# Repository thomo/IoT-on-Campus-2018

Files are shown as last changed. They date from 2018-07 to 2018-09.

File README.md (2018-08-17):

Boards, sources and configuration to run the Mini-Hackathon at SQS Campus 2018.
The infrastructure consists of two kind of ESP8266 nodes - called NodeA and NodeB - and a master. The master is running on a Raspberry Pi 3. On the master a bundle of applications is installed:
- Mosquitto - a MQTT server
- Influxdb - a time based database
- Grafana 
- NodeRed

The NodeA/NodeB are small IoT devices with a temperature/humidity/pressure sensor, two switches and some RGB leds. While NodeA is prebuild and will be distributed on the campus location to collect sensor data the NodeB will be put together by the participants in a workshop.

## Setup Arduino for ESP8266

(Source: https://github.com/esp8266/Arduino)

- Install the current upstream Arduino IDE at the 1.8 level or later. The current version is at the Arduino website.
- Start Arduino and open Preferences window.
- Enter http://arduino.esp8266.com/stable/package_esp8266com_index.json into Additional Board Manager URLs field. You can add multiple URLs, separating them with commas.
- Open Boards Manager from Tools > Board menu and install esp8266 platform (and don't forget to select your ESP8266 board from Tools > Board menu after installation).

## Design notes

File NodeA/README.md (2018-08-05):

# Circuit

A ESP8266 node with
- 2x WS2812A RGB LEDs, DIN on D5 (GPIO14)
- 2x switchs on D6 (GPIO12) and D7 (GPIO13) with 10k pull-ups
- 1x BME280, SCL on D1 (GPIO05) and SDL on D2 (GPIO04)

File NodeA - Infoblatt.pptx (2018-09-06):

## IoT (Internet of Things) – Node A SQS – Blackbox – Umwelt- und Sensordaten Infoblatt

- IoT Hackathon

© SQS Software Quality Systems AG | IoT Hackathon | Intern | Version 1.0 |

Push the Buttons

Messung von Temperatur, Luftfeuchtigkeit und Luftdruck im Raum

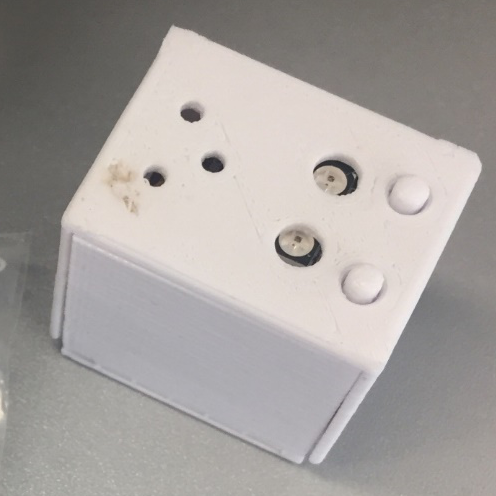
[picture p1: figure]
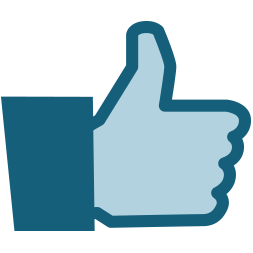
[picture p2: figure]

IoT WLAN:
SSID: “IoT Campus”
PW: “campus2018”
→ http://10.0.0.1:1880/ui

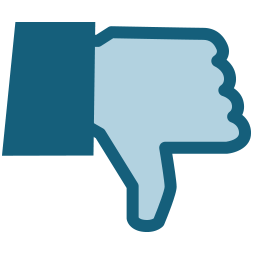
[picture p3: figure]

*Im Raum sind 6 NodeA verfügbar, welche über WLAN mit einem MQTT-Broker kommunizieren

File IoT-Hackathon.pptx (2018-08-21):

## IoT-Hackathon

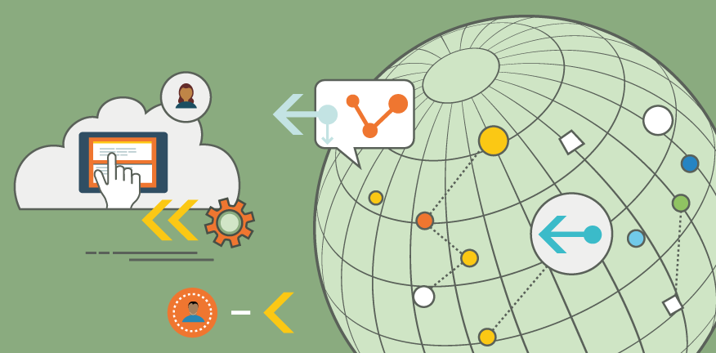
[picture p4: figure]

Transforming the World Through Quality

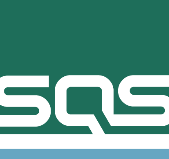
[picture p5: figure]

sqs.com

## Systemübersicht

© SQS Software Quality Systems AG | IoT Hackathon | Intern | Version 1.0 |

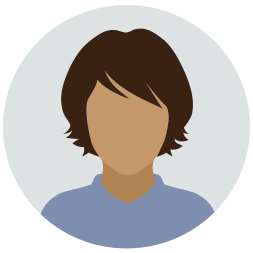
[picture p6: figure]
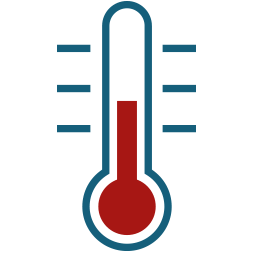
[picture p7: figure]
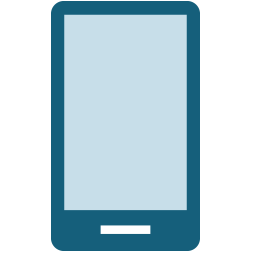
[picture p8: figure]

Sensor
BME280
Temperatur
Feuchtigkeit
Druck

Onewire

Sensor
Taster
2x

DIGITAL

Aktor
RGB LED
2x bzw.
LED Ring

DIGITAL

MQTT Publisher &
Subscriber
Node-Red
Raspberry PI

DASHBOARD
GRAFANA
Raspberry PI

MQTT Publisher
& Subscriber
WEMOS D1
ESP8266
NodeA / NodeB

MQTT

MQTT

HTTP

MQTT

MQTT Broker
Mosquitto
Raspberry PI

TIMEBASED DB
INFLUXDB
Raspberry PI

MQTT

HTTP

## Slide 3

NodeA

NodeA

NodeA

NodeA

NodeA

NodeA

Node-Red

GRAFANA

MOSQITTO

INFLUX DB

NodeB

NodeB

NodeB

NodeB

NodeB

NodeB

NodeB

NodeB

## Node A - Hardware

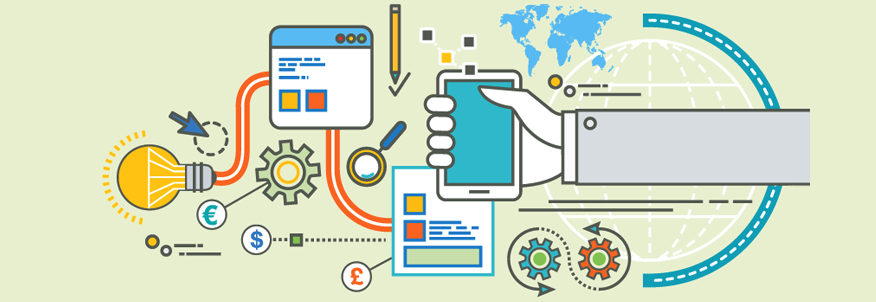
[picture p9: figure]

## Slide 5

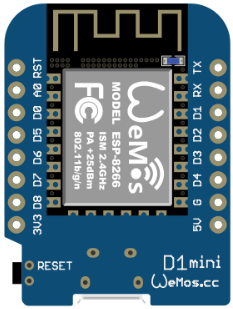
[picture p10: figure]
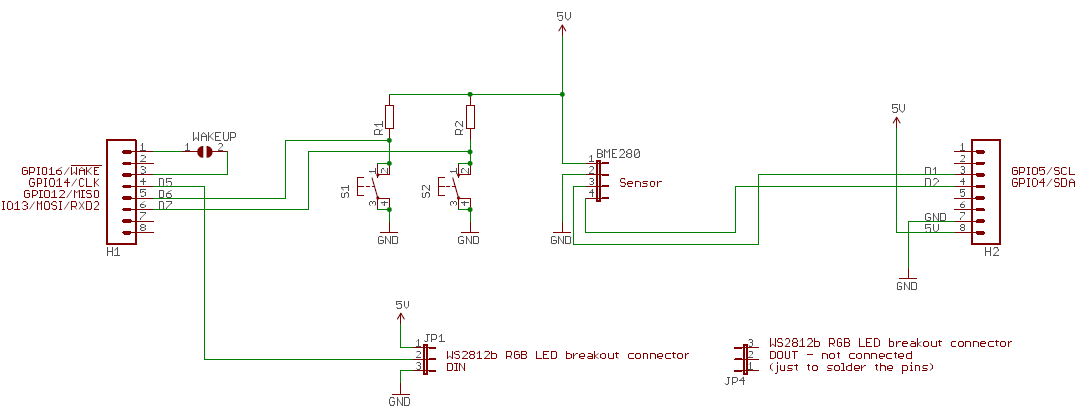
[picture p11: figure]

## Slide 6

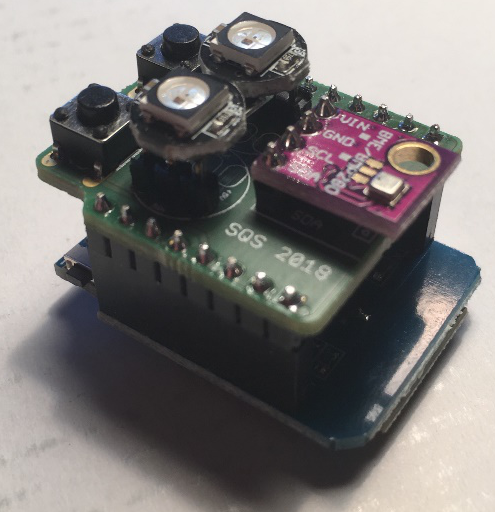
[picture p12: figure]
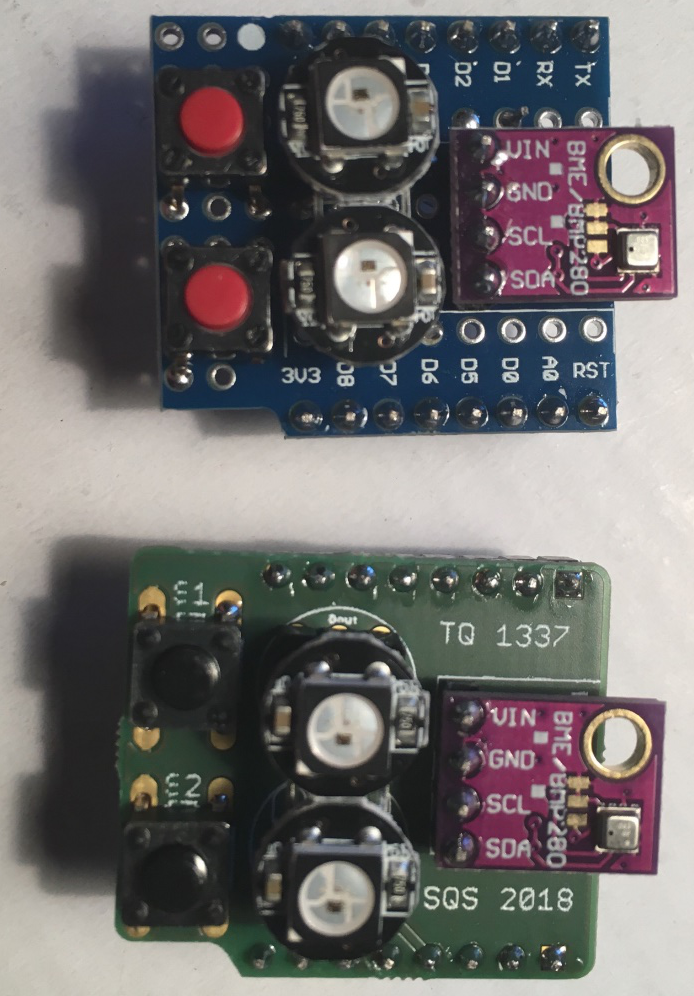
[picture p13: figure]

## Node B - Hardware

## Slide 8

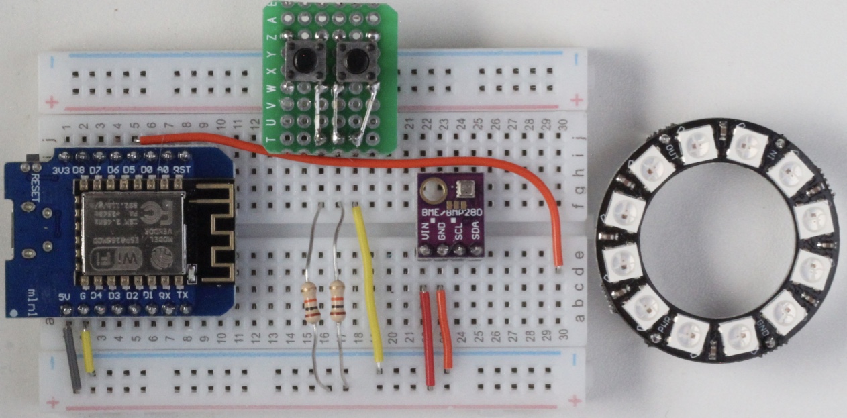
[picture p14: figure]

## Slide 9

IN

PWR

GND

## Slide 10

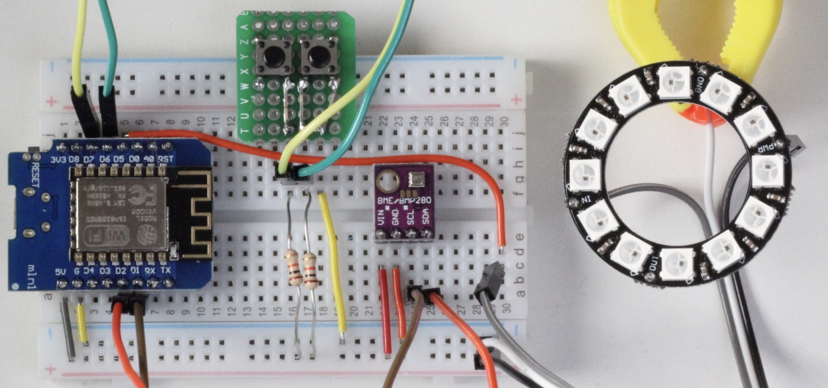
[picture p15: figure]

## Software

## Programmierung mit der Arduino Entwicklungsumgebung

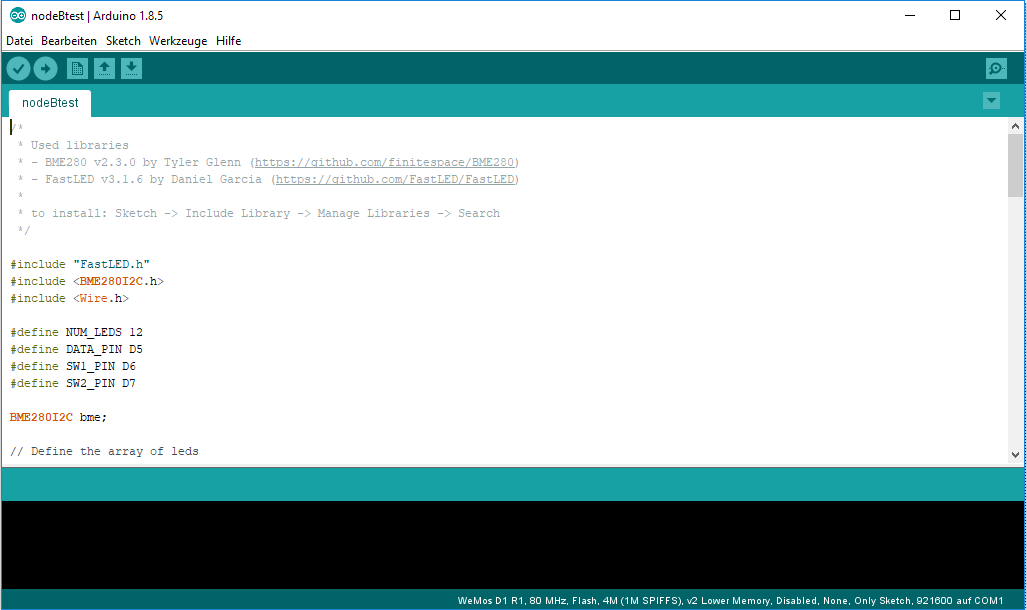
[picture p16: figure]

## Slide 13

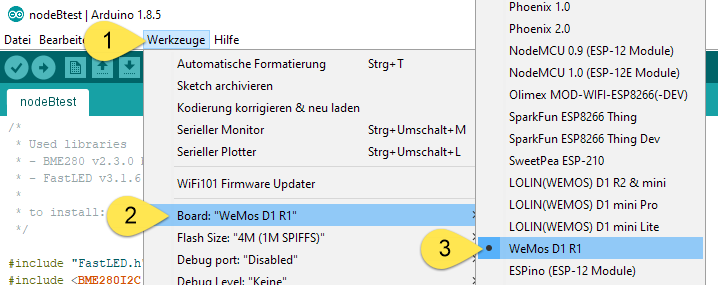
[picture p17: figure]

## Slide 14

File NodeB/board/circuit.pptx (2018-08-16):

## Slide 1


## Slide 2

IN

PWR

GND

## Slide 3


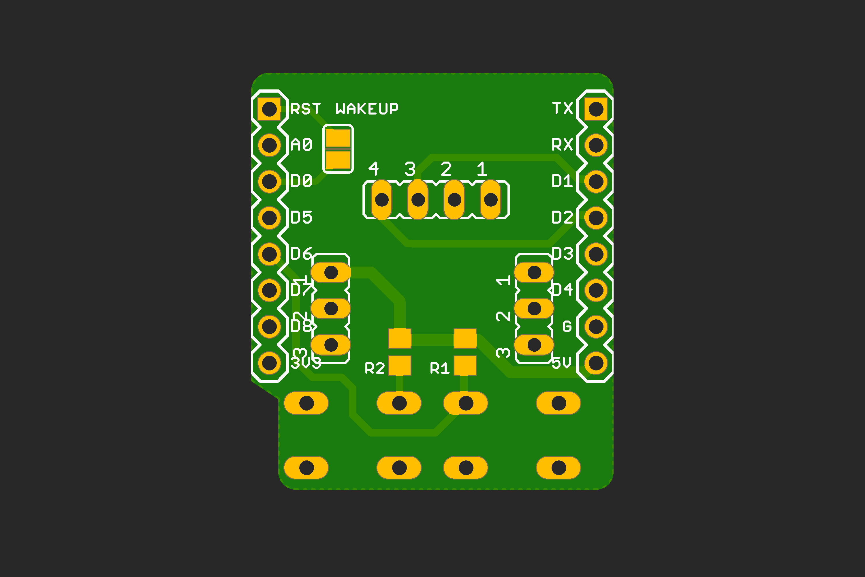
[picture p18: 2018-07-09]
NodeA/board/bottom.png

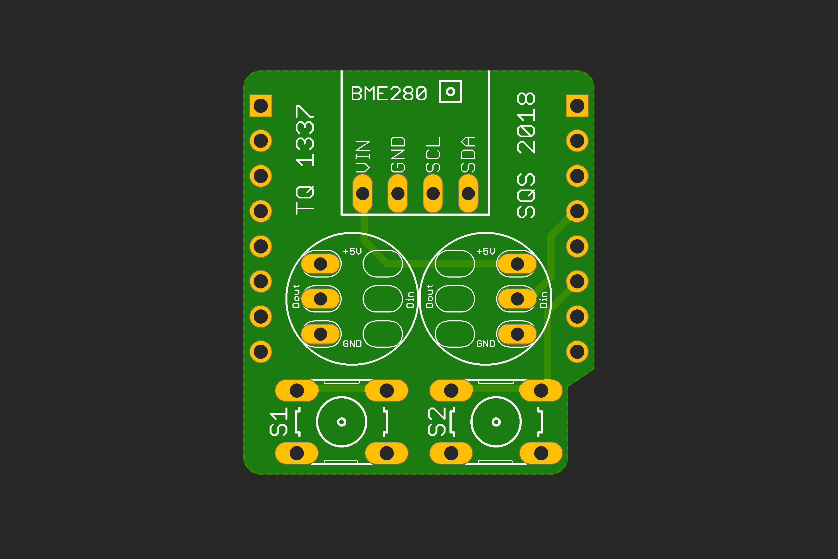
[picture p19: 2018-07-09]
NodeA/board/top.png

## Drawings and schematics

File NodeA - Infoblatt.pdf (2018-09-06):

### IoT (Internet of Things) – Node A SQS – Blackbox – Umwelt- und Sensordaten Infoblatt

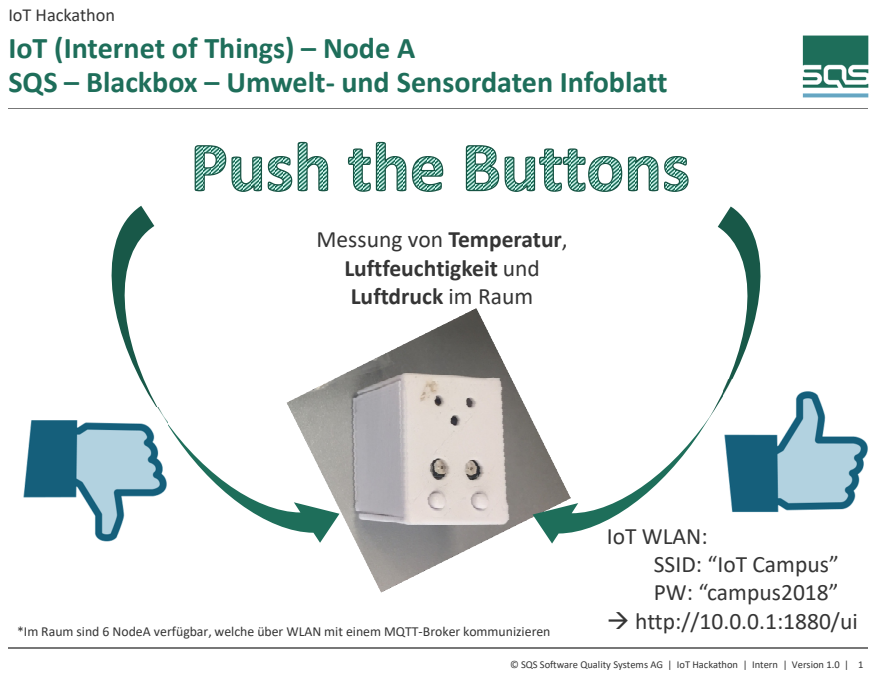
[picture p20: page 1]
IoT Hackathon

Messung von Temperatur,
Luftfeuchtigkeit und
Luftdruck im Raum

IoT WLAN:
SSID: “IoT Campus”
PW: “campus2018”
 http://10.0.0.1:1880/ui

*Im Raum sind 6 NodeA verfügbar, welche über WLAN mit einem MQTT-Broker kommunizieren

© SQS Software Quality Systems AG | IoT Hackathon | Intern | Version 1.0 | 1

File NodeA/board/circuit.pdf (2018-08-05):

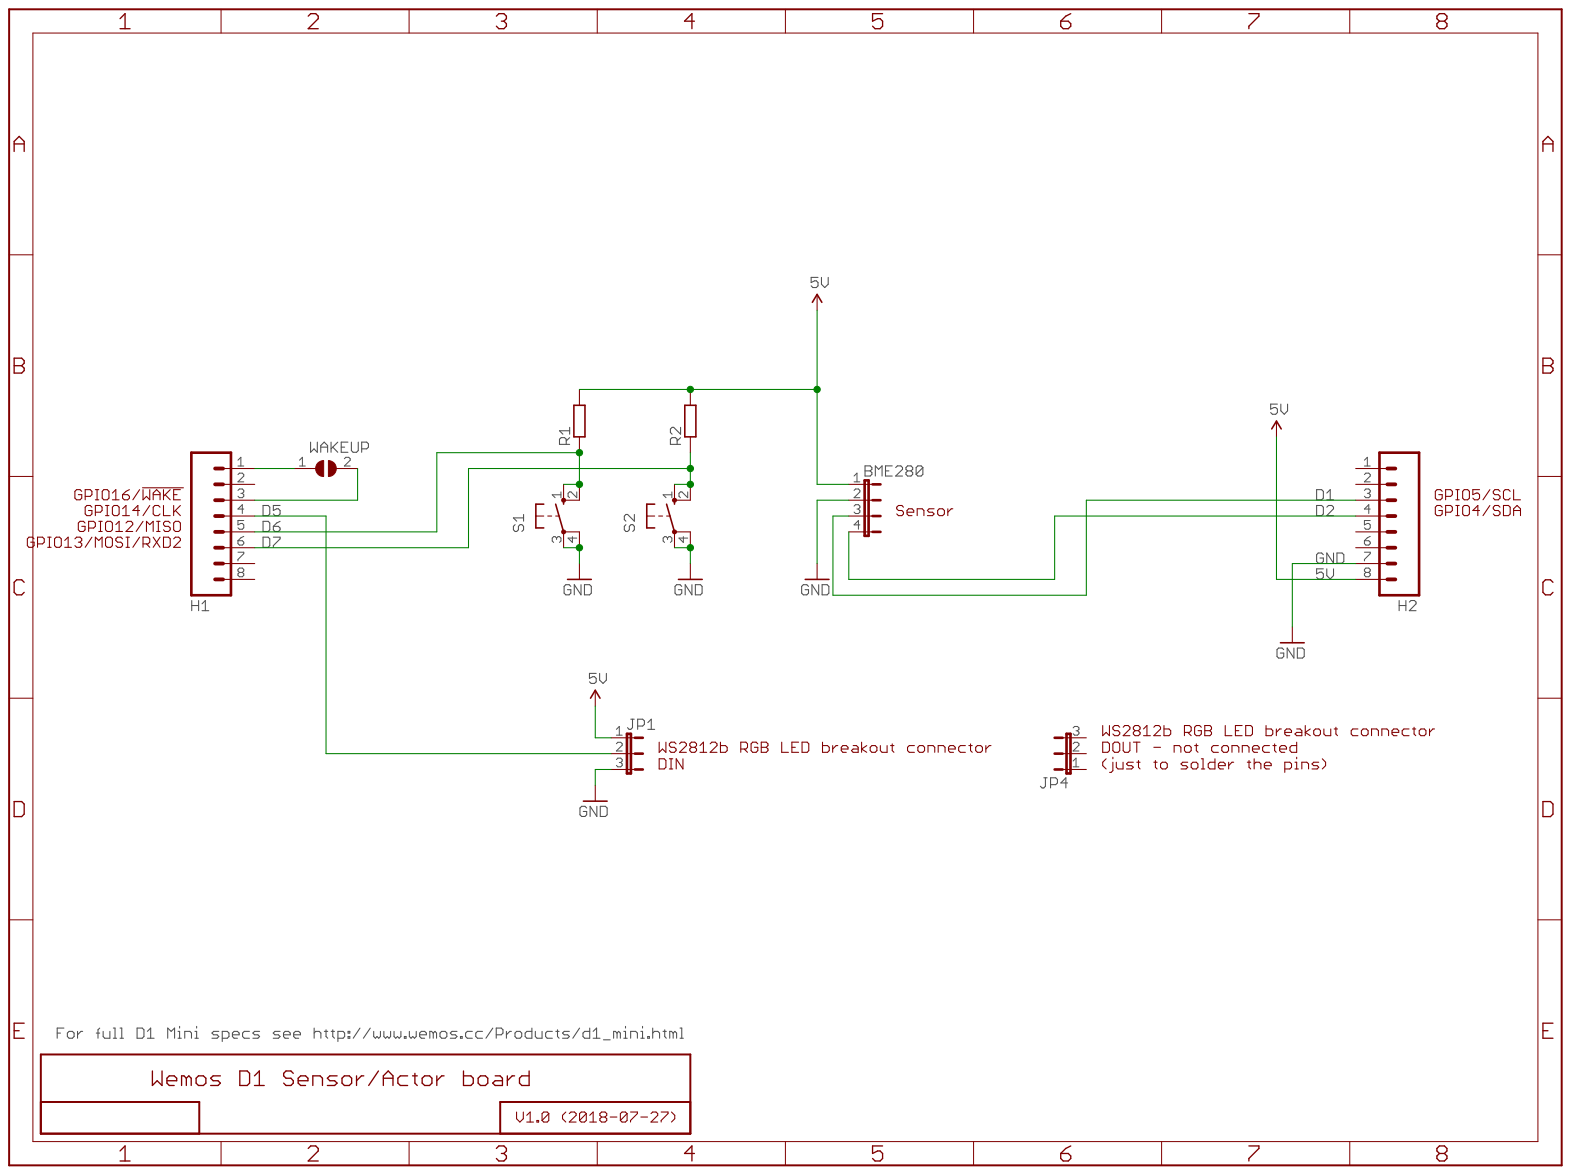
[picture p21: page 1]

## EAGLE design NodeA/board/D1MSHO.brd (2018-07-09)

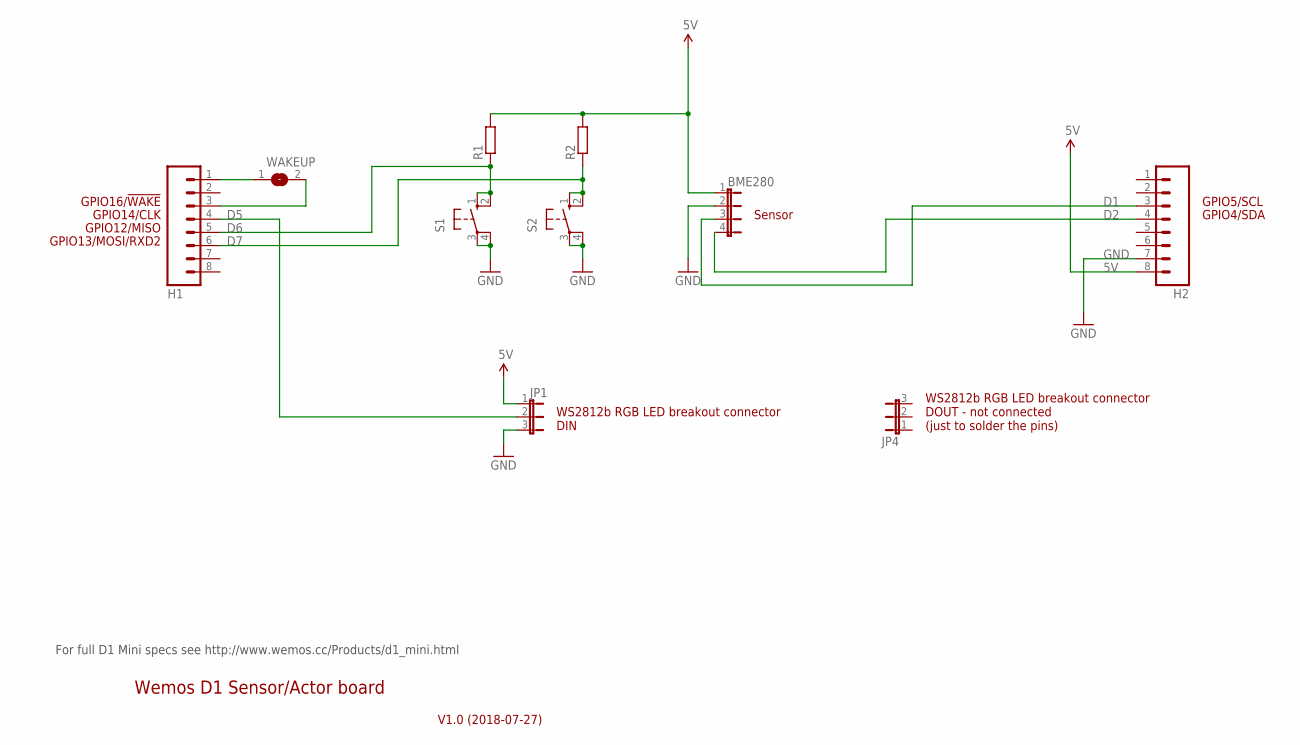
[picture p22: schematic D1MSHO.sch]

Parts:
BME280: JP4E; JP4
H1, H2: M08; 1X08
JP1, JP4: JP2E; JP2
R1, R2: R-EU_R0805; R0805
S1, S2: 10-XX; B3F-10XX
WAKEUP: SJ

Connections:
5V: BME280.1, H2.8, JP1.1, R1.2, R2.2
D1: BME280.3, H2.3
D2: BME280.4, H2.4
D5: H1.4, JP1.2
D6: H1.5, R1.1, S1.1 (S), S1.2 (S1)
D7: H1.6, R2.1, S2.1 (S), S2.2 (S1)
GND: BME280.2, H2.7, JP1.3, S1.3, S1.4 (P1), S2.3, S2.4 (P1)
unnamed: H1.1, WAKEUP.1
unnamed: H1.3, WAKEUP.2

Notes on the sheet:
GPIO12/MISO
GPIO4/SDA
GPIO5/SCL
GPIO13/MOSI/RXD2
GPIO14/CLK
GPIO16/!WAKE
V1.0 (2018-07-27)
For full D1 Mini specs see http://www.wemos.cc/Products/d1_mini.html
Wemos D1 Sensor/Actor board
WS2812b RGB LED breakout connector DIN
WS2812b RGB LED breakout connector DOUT - not connected (just to solder the pins)
Sensor

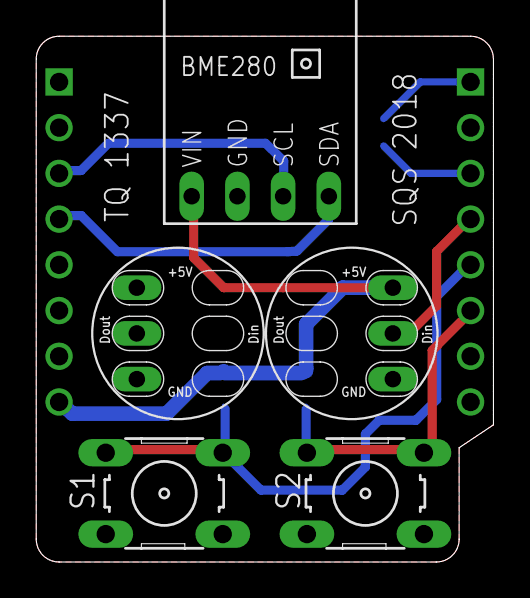
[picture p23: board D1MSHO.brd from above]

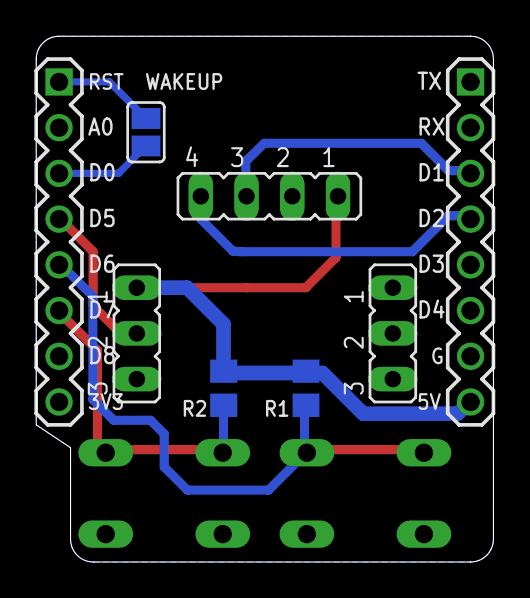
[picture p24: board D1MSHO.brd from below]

Board: 2 copper layers, 25.4 x 29.2 mm, 12 parts (8 on the bottom side), 9 nets.

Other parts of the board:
U$2, U$4: WS2812BBOARD

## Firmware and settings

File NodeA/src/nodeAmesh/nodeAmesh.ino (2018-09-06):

/*
 * Used libraries
 * - BME280 v2.3.0 by Tyler Glenn (https://github.com/finitespace/BME280)
 * - FastLED v3.1.6 by Daniel Garcia (https://github.com/FastLED/FastLED)
 * - WifiManager v0.14.0 by tzapu (https://github.com/tzapu/WiFiManager)
 * - ArduinoJson v5.13.2 (! use this version)
 * - PubSubClient by Nick O'Leary 2.6.0 (https://pubsubclient.knolleary.net/)
 * 
 * to install: Sketch -> Include Library -> Manage Libraries -> Search 
 */

#include <FS.h>                   //this needs to be first, or it all crashes and burns...

#include "FastLED.h"
#include <BME280I2C.h>
#include <Wire.h>

#include <ESP8266WiFi.h>          //ESP8266 Core WiFi Library (you most likely already have this in your sketch)

#include <DNSServer.h>            //Local DNS Server used for redirecting all requests to the configuration portal
#include <ESP8266WebServer.h>     //Local WebServer used to serve the configuration portal
#include <WiFiManager.h>          //https://github.com/tzapu/WiFiManager WiFi Configuration Magic

#include <ArduinoJson.h>          //https://github.com/bblanchon/ArduinoJson

#include <PubSubClient.h>

#define MY_DEBUG  1

#define NUM_LEDS  2
#define LEFT_LED  1
#define RIGHT_LED 0
#define DATA_PIN  D5
#define SW0_PIN   D6
#define SW1_PIN   D7

#define DEFAULT_MQTT_SERVER "mqttbroker"
#define DEFAULT_NODE_ID "white"
#define DEFAULT_COLOR "1_1_1"

#define SUB_TOPIC "campus/feedback"
#define PUB_TOPIC "campus/nodeA"
#define PUB_BTN0STATE "campus/Button0"
#define PUB_BTN1STATE "campus/Button1"

const char* mqtt_user = "tq";
const char* mqtt_password = "campus2018";

WiFiClient espClient;
PubSubClient mqttClient(espClient);

BME280I2C bme;

CRGB leds[NUM_LEDS];

const CRGB LED_OFF  = CRGB(0,0,0);
const CRGB LED_RED  = CRGB(181,0,0);
const CRGB LED_GREEN = CRGB(0,181,0);
const CRGB LED_BLUE = CRGB(0,0,181);

char cfg_node_id[20];
char cfg_mqtt_server[40];
char cfg_color[12];

//flag for saving data
bool shouldSaveConfig = false;

long lastMsgMillis = 0;

//          1         2         3         4         5         6         7         8         9         0         1         2
// 123456789012345678901234567890123456789012345678901234567890123456789012345678901234567890123456789012345678901234567890
// sensors node=12345678901234567890 temp=-xx.xx,hum=100.00,press=100000.00,s0=x,s1=x,color=xxx_xxx_xxx
#define MQTT_MSG_LEN 120
#define MQTT_BTN_LEN 22
char mqttMsg[MQTT_MSG_LEN];
char mqttButtonMsg[MQTT_BTN_LEN];

// ------------------------------------------------------

//callback notifying us of the need to save config
void saveConfigCallback () {
  shouldSaveConfig = true;
}

void saveConfig () {
  DynamicJsonBuffer jsonBuffer;
  JsonObject& json = jsonBuffer.createObject();
  json["mqtt_server"] = cfg_mqtt_server;
  json["node_id"] = cfg_node_id;
  json["color"] = cfg_color;

  File configFile = SPIFFS.open("/config.json", "w");
  if (!configFile) {
    Serial.println("failed to open config file for writing");
  } else {
    json.printTo(configFile);
    configFile.close();
  }
  //end save
}

void loadConfig() {
  //read configuration from FS json
  if (SPIFFS.exists("/config.json")) {
    //file exists, reading and loading
    Serial.println("reading config file");
    File configFile = SPIFFS.open("/config.json", "r");
    if (configFile) {
      size_t size = configFile.size();
      // Allocate a buffer to store contents of the file.
      std::unique_ptr<char[]> buf(new char[size]);

      configFile.readBytes(buf.get(), size);
      DynamicJsonBuffer jsonBuffer;
      JsonObject& json = jsonBuffer.parseObject(buf.get());
      if (json.success()) {
        strncpy(cfg_mqtt_server, json["mqtt_server"], 40);
        strncpy(cfg_node_id, json["node_id"], 20);
        strncpy(cfg_color, json["color"], 12);
      } else {
        Serial.println("Failed to load json config. Invalid?");
        json.printTo(Serial);
        Serial.println("\n");
      }
      configFile.close();
    }
  } else {
    Serial.println("config file not found!");
  }
}

void runConfig() {
    // Local intialization. Once its business is done, there is no need to keep it around
    WiFiManager wifiManager;
    wifiManager.setDebugOutput(false);

    WiFiManagerParameter labelMQTT("<label for=\"srv\">MQTT broker (hostname or ip)</label>");
    wifiManager.addParameter(&labelMQTT);
    WiFiManagerParameter custom_mqtt_server("srv", "mqtt broker", cfg_mqtt_server, 40);
    wifiManager.addParameter(&custom_mqtt_server);

    WiFiManagerParameter labelID("<label for=\"nid\">Node Id</label>");
    wifiManager.addParameter(&labelID);
    WiFiManagerParameter custom_node_id("nid", "node id", cfg_node_id, 20);
    wifiManager.addParameter(&custom_node_id);
    
    WiFiManagerParameter labelColor("<label for=\"color\">Color (xxx_xxx_xxx)</label>");
    wifiManager.addParameter(&labelColor);
    WiFiManagerParameter custom_color("color", "color", cfg_color, 12);
    wifiManager.addParameter(&custom_color);
    
    // set config save notify callback
    wifiManager.setSaveConfigCallback(saveConfigCallback);
  
    if (!wifiManager.startConfigPortal("NodeConfigWiFi")) {
      Serial.println("failed to connect and hit timeout");
      delay(3000);
      //reset and try again, or maybe put it to deep sleep
      ESP.reset();
      delay(5000);
    }

    // if you get here you have connected to the WiFi
    Serial.println("connected ... :)");

    if (shouldSaveConfig) {
      // read updated parameters
      strncpy(cfg_mqtt_server, custom_mqtt_server.getValue(), 40);
      strncpy(cfg_node_id, custom_node_id.getValue(), 20);
      strncpy(cfg_color, custom_color.getValue(), 12);
  
      saveConfig(); 
    }
}

void setupWiFi() {
  Serial.println("Start WiFi Setup");

  WiFi.persistent(false); // just store updated ssid/passwd values
  WiFi.begin(); // connect using the ssid/passwd configured with wifi manager

  int cnt = 0;
  while (WiFi.status() != WL_CONNECTED && cnt < 10) {
    ++cnt;
    delay(500);
    Serial.print(".");
  }  

  if (WiFi.status() == WL_CONNECTED) {
    Serial.println("\nWiFi connected");
    Serial.println("IP address: ");
    Serial.println(WiFi.localIP());
  } else {
    Serial.println("\nERROR: WiFi connection failed!");
    leds[0] = LED_RED;
  }
  Serial.println("----- ----- -----");
}

void setupMQTT() {
  Serial.println("Start MQTT Setup");
  mqttClient.setServer(cfg_mqtt_server, 1883);
  mqttClient.setCallback(mqttCallback);
}

void setupBME() {
  Wire.begin();

  int cnt = 0;
  while (!bme.begin() && cnt < 10) {
    ++cnt;
    Serial.println("Could not find BME280 sensor!");
    delay(1000);
  }

  if (!bme.begin()) {
    Serial.println("Could not find BME280 sensor! - Giving up :-(");
  }
}

int splitColorString(char* color, char* buf) {
  int idx = 0;
  while ((color[idx] != '_') && (color[idx] != '\0')) {
    buf[idx] = color[idx];
    ++idx;
  }
  buf[idx] = '\0';
  return idx;
}

void parseRGB(char* color, CRGB* rgb) {
  int idx = 0;
  char tmp[4];
  
  idx = idx + splitColorString(color, tmp);
  rgb->r = atoi(tmp);

  ++idx;
  idx = idx + splitColorString(&color[idx], tmp);
  rgb->g = atoi(tmp);
  
  ++idx;
  idx = idx + splitColorString(&color[idx], tmp);
  rgb->b = atoi(tmp);
}

void setup() {
  Serial.begin(115200);
  Serial.println();

  FastLED.addLeds<WS2812B, DATA_PIN, GRB>(leds, NUM_LEDS);

  // set default values
  strncpy(cfg_mqtt_server, DEFAULT_MQTT_SERVER, 40);
  strncpy(cfg_node_id, DEFAULT_NODE_ID, 20);
  strncpy(cfg_color, DEFAULT_COLOR, 12);

  if (!SPIFFS.begin()) {
    Serial.println("failed to mount FS");
  }

  if (digitalRead(SW1_PIN) == HIGH) {
    loadConfig();
  }
  
  if (digitalRead(SW0_PIN) == LOW) {
    leds[0] = LED_BLUE;
    leds[1] = LED_BLUE;
    FastLED.show();

    runConfig();

    // will not reach this line - restart of ESP8266 is forced in runConfig() !!!
  }
  
  parseRGB(cfg_color, &leds[0]);
  parseRGB(cfg_color, &leds[1]);

  setupWiFi();
  setupMQTT();
  setupBME();
  
  FastLED.show();
}

void mqttCallback(char* topic, byte* payload, unsigned int length) {
  if (MY_DEBUG) {
    Serial.print("< [");
    Serial.print(topic);
    Serial.print("] ");
    for (int i = 0; i < length; i++) {
      Serial.print((char)payload[i]);
    }
    Serial.println();
  }

  // incoming payload: nodeName=rrr_ggg_bbb or x=rrr_ggg_bbb  (x=0 or x=1)
  
  if (strcmp(topic,SUB_TOPIC)==0) {
    // content contains color of led 0 and led 1
    // adjust the color of leds accordingly

    // get node name length and color length
    char* pos = strstr((char*)payload, "=");    
    int nodeNameLength = 0;
    nodeNameLength = pos - (char*)payload;
    int colorLength = length - nodeNameLength - 1;

    pos++;
    char cbuf[12];
    strncpy(cbuf, pos, colorLength);
    cbuf[min(11U,length-nodeNameLength-1)] = '\0';
    Serial.print("cbuf=");
    Serial.println(cbuf);
    char node[20];
    int j = 0;

    for (int i = 0; i < length; i++) {
      if (payload[i] == '=') break;
      node[j++] = payload[i];
    }
    
    node[j]='\0';

    // if NODE=R_G_B -> LED 0 and LED 1
    // if x=R_G_B -> LED 0 or LED 1

    if (strcmp(node, cfg_node_id) == 0) {
      parseRGB(cbuf, &leds[LEFT_LED]);
      parseRGB(cbuf, &leds[RIGHT_LED]);
      FastLED.show();
    }
    else if (payload[0] == '0') {
      parseRGB(cbuf, &leds[LEFT_LED]);
      FastLED.show();
    }
    else if (payload[0] == '1') {
      parseRGB(cbuf, &leds[RIGHT_LED]);
      FastLED.show();
    }
  }
}

void mqttReconnect() {
  // Loop until we're reconnected
  while (!mqttClient.connected()) {
    
    Serial.print("Attempting MQTT connection ... ");
    
    // Attempt to connect
    if (mqttClient.connect(WiFi.macAddress().c_str(), mqtt_user, mqtt_password)) {
      Serial.println("connected");
      mqttClient.subscribe(SUB_TOPIC);
    } else {
      Serial.print("failed, rc=");
      Serial.print(mqttClient.state());
      Serial.println(" try again in some seconds");
      delay(2000);       // Wait before retrying
    }
  }
}

int btn0State = HIGH;
int btn1State = HIGH;
int lastClickMillis = 0;

void publishButtonState() {
  long now = millis();  
  if (now - lastClickMillis > 75) {
    lastClickMillis = now;
    
    int currentBtn0State = digitalRead(SW0_PIN);

    if (currentBtn0State == LOW && btn0State == HIGH) {
      btn0State = LOW;
      Serial.println("Button 0 pressed");
      snprintf (mqttButtonMsg, MQTT_BTN_LEN, "%s#%d#%s", cfg_node_id, btn0State, cfg_color);
      mqttClient.publish(PUB_BTN0STATE, mqttButtonMsg);
    }
    else if (currentBtn0State == HIGH && btn0State == LOW) {
      Serial.println("Button 0 released");
      btn0State = HIGH;
    }
    
    int currentBtn1State = digitalRead(SW1_PIN);
  
    if (currentBtn1State == LOW && btn1State == HIGH) {
      btn1State = LOW;
      Serial.println("Button 1 pressed");
      snprintf (mqttButtonMsg, MQTT_BTN_LEN, "%s#%d#%s", cfg_node_id, btn1State, cfg_color);
      mqttClient.publish(PUB_BTN1STATE, mqttButtonMsg);
    }
    else if (currentBtn1State == HIGH && btn1State == LOW) {
      Serial.println("Button 1 released");
      btn1State = HIGH;
    }
  }
}

void publishSensorData() {
  long now = millis();
  if (now - lastMsgMillis > 2000) {
    lastMsgMillis = now;

    float temp(NAN), hum(NAN), pres(NAN);

    BME280::TempUnit tempUnit(BME280::TempUnit_Celsius);
    BME280::PresUnit presUnit(BME280::PresUnit_Pa);

    bme.read(pres, temp, hum, tempUnit, presUnit);
    
    snprintf (mqttMsg, MQTT_MSG_LEN, 
              "sensors,node=%s temp=%.2f,hum=%.2f,press=%.2f,s0=%d,s1=%d,color=\"%s\"", 
              cfg_node_id, temp, hum, pres, digitalRead(SW0_PIN), digitalRead(SW1_PIN), cfg_color);
    if (MY_DEBUG) {
      Serial.print("> [");
      Serial.print(PUB_TOPIC);
      Serial.print("] ");
      Serial.println(mqttMsg);
    }
    mqttClient.publish(PUB_TOPIC, mqttMsg);
  }
}

void loop(void) {
  if (!mqttClient.connected()) {
    mqttReconnect();
  }
  mqttClient.loop();
  publishSensorData();
  publishButtonState();
}

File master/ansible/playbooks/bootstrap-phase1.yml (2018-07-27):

---

# Bootstraping a new Raspberry Pi - phase 1

- hosts: newhosts
  become: True
  vars:
    ansible_user: pi

  tasks:
    - name: Set timezone
      lineinfile:
        dest: /etc/timezone
        regexp: ^.*$
        line: 'Europe/Berlin'
      tags: [ 'raspiconfig' ]

    - name: Enable locale definitions
      lineinfile:
        dest: /etc/locale.gen
        regexp: "^# ({{item}}.*)$"
        line: '\1'
        backrefs: yes
      with_items: ['de_DE ISO-8859-1' , 'de_DE.UTF-8', 'en_US.UTF-8' ]
      tags: [ 'raspiconfig', 'locale' ]

    - name: Generate locale files
      command: /usr/sbin/locale-gen
      tags: [ 'raspiconfig', 'locale' ]

    - name: Set locale LANG env
      command: /usr/sbin/update-locale LANG=en_US.UTF-8
      tags: [ 'raspiconfig', 'locale' ]

    - name: Remove packages not needed
      apt: name={{ item }} state=absent purge=yes autoremove=yes
      with_items: "{{ raspi_apt_unneeded_packages }}"
      tags: [ 'cleanup' ]

    - name: Delete demo and test files
      file: path={{ item }} state=absent
      with_items: "{{ stuff_to_remove }}"
      tags: [ 'cleanup' ]

    - name: Remove dependencies that are no longer required
      apt: autoremove=yes
      tags: [ 'apt', 'cleanup' ]

    - name: Update APT package cache
      apt: update_cache=yes
      tags: [ 'apt' ]

    - name: Upgrade APT to the lastest packages
      apt: upgrade=safe
      tags: [ 'apt' ]

    - name: Add SSH authorized key for pi user
      authorized_key: user=pi key="{{ lookup('file', '../files/iot_master.pub') }}"
      tags: [ 'ssh' ]

    - name: Disable password authentication for ssh
      lineinfile:
        dest: /etc/ssh/sshd_config
        regexp: "^{{ item.regexp }}"
        line: "{{ item.line }}"
        insertafter: "^#{{ item.regexp }}"
      with_items:
        - { regexp: 'PasswordAuthentication\s+', line: 'PasswordAuthentication no'}
        - { regexp: 'ChallengeResponseAuthentication\s+', line: 'ChallengeResponseAuthentication no'}
      tags: [ 'ssh' ]

    - name: Disable xconsole output
      replace:
        dest: /etc/rsyslog.conf
        regexp: '^# The named pipe /dev/xconsole.*\n(.*\n)*\s+.*\|/dev/xconsole\s*$'
        replace: ''
      tags: [ 'config' ]

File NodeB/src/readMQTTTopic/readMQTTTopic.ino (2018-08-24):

/*
 * Used libraries
 * - PubSubClient by Nick O'Leary 2.6.0 (https://pubsubclient.knolleary.net/)
 * 
 * to install: Sketch -> Include Library -> Manage Libraries -> Search 
 */
 
#include <ESP8266WiFi.h>
#include <PubSubClient.h>

const char* ssid = "";
const char* password = "";
const char* mqtt_server = "";
const char* mqtt_user = "tq";
const char* mqtt_password = "campus2018";

WiFiClient espClient;
PubSubClient client(espClient);

void setup() {
  delay(2000);
  Serial.begin(115200);
  
  setup_mqtt();
}

void setup_mqtt()
{
  Serial.println("Starte MQTT Setup");
  pinMode(BUILTIN_LED, OUTPUT);     // Initialize the BUILTIN_LED pin as an output
  setup_wifi();
  client.setServer(mqtt_server, 1883);
  client.setCallback(callback);
  Serial.println("----- ----- -----");
}

void setup_wifi() {
  Serial.println("Starte WiFi Setup");
  delay(10);
  // We start by connecting to a WiFi network
  Serial.println();
  Serial.print("Connecting to ");
  Serial.println(ssid);

  WiFi.begin(ssid, password);

  int c = 0;
  while (WiFi.status() != WL_CONNECTED && 10 > c++)
  {
    delay(500);
    Serial.print(".");
  }  

  Serial.println("");
  Serial.println("WiFi connected");
  Serial.println("IP address: ");
  Serial.println(WiFi.localIP());
  Serial.println("----- ----- -----");
}

void callback(char* topic, byte* payload, unsigned int length) {
  Serial.print("Message arrived [");
  Serial.print(topic);
  Serial.print("] ");
  for (int i = 0; i < length; i++) {
    Serial.print((char)payload[i]);
  }
  Serial.println();

  if (strcmp(topic,"ledStatus")==0) {
    // Switch on the LED if an 1 was received as first character
    if ((char)payload[0] == '1') {
      digitalWrite(BUILTIN_LED, LOW);   // Turn the LED on (Note that LOW is the voltage level
      // but actually the LED is on; this is because
      // it is acive low on the ESP-01)
    } else {
      digitalWrite(BUILTIN_LED, HIGH);  // Turn the LED off by making the voltage HIGH
    }
  }
 
  if (strcmp(topic,"home/basement/work/temperatur")==0) {
    Serial.println("to something based on the temperature");
  }
}

void reconnect() {
  // Loop until we're reconnected
  while (!client.connected()) {
    Serial.print("Attempting MQTT connection...");
    // Attempt to connect
    if (client.connect(WiFi.macAddress().c_str(), mqtt_user, mqtt_password)) {
      Serial.println("connected");
      // ... and subscribe to one or more topics
      client.subscribe("ledStatus");
      client.subscribe("home/basement/#");
    } else {
      Serial.print("failed, rc=");
      Serial.print(client.state());
      Serial.println(" try again in 5 seconds");
      // Wait 5 seconds before retrying
      delay(5000);
    }
  }
}

void loop() {
  if (!client.connected()) {
    reconnect();
  }
  client.loop();
} 

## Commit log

2018-07-09 init with NodeA
    [D1MSHO.brd, D1MSHO.sch]
2018-07-09 add board images
2018-08-05 set board name and export circuit
    [D1MSHO.sch]
2018-08-05 move board files to sub dir
    [D1MSHO.brd, D1MSHO.sch]
2018-08-15 init version. connect to mqtt server; publish topic with switch value each call
2018-08-16 Program for testing the wiring of a NodeB
2018-08-17 short overview and notes about arduino setup
2018-08-17 init example; led ring switches from red, green, blue
2018-08-20 init checkin of untested example. Buttons can be used to switch LEDs in Ring (left/right direction)
2018-08-20 init checkin of untested example. Buttons can be used to switch on the onboard LED
2018-08-29 added node red flow as json string
2018-09-01 Alternative versions for NodeA and NodeRed NodeA: Loop handles now both button clicks separately and sending the to /campus/Button0 or /campus/Button1. callback function now reads either 1=r_g_b or n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
2018-09-05 add circuits to nodes and nodeA firmware description
2018-09-05 added rating flow for node red added rating functionality to nodeA
2018-09-06 publish button state and sub feedback topic
2018-09-06 added rating to TQ flow
2018-09-06 final Node Red flow with evaluation

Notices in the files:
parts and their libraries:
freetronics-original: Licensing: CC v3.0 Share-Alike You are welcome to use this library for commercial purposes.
